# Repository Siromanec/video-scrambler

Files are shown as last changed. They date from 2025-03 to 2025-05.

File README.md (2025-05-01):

# video-scrambler
This repository is for "Development of a Composite Baseband Video Signal (CVBS) scrambler" thesis.

## Description

This project contains:
 - Verilog HDL implementation (Quartus Prime 23.1std project) 
 - simulation setup (Modelsim Starter Edition 2021.1 project)
 - jupyter notebooks for visualization and validation of the algorithms
 - KiCAD 9.0 PCB designs for ADV7393 video encoder and TVP5147M1 video decoder

The Verilog implementation is based around line rotation algorithm for scrambling, 
Hash DRBG and SHA256 for number generation. 
It works with BT656 and SMPTE293M digital signal. 
Can synchronise the PRNGs even when the signal is lost. 
The scrambling pattern is different for each frame.
The number of frames before the pattern repeats is 2^32.
The delay is ~ 10^-8 s

The PCB design has the following features:
 - supplied with \> 5V
 - has 4 layers
 - separated power plains
 - all chips pins were wired to external pins (except chroma pins)
 - equalized paths

## Structure and  use
To open each project you need the corresponding IDE
### Notebooks
#### 1. `notebooks/config_creation`

It contains scripts for generating 256-bit seeds and putting them into `.mif` files for configuring the scrambler.

Generates complementary config files for the scrambler and descramber,
#### 2. `notebooks/functional_validation`
It was used to rewrite high-level python implementation
into verilog-friendly algorithm
#### 3. `notebooks/mp_to_bt656`

It contains a notebook used for converting `.mp4` video to `.bin` file compliant with bt656.

Additionally, it is used for visualization the scrambled and descrambled videos and contains the entropy calculations

Also, it has two videos: `aperol.mp4` and `church.mp4`. 
For simulation the user must convert the videos to
`aperol_f84.bin` and `church_f218.bin` and put them into

`FPGA/core/simulation/modelsim/data` or `FPGA/core/simulation/questa/data`

#### 4. `notebooks/randomness_validation`
It was used to validate that the generated random numbers are random
#### 5. `notebooks/resource_usage`
It was used to produce plots of resource usage as compiled by Quartus

### Verilog HDL implementation

`scrambler_mm` is the top module

`FPGA/core` contains the quartus project

`FPGA/core/src` contains rtl and tb code

`FPGA/core/include` contains rtl written by other developers

### Simulation setup

`FPGA/core/simulation/modelsim` contains the modelsim project

To provide the data for the simulation 
you must put it into `FPGA/core/simulation/modelsim/data`.
currently the simulations accepts only two types of files: files generated from `aperol_f84.bin` or `church_f218.bin`.
if you want to change it, you must modify the testbench with names of your files.
Once they are in there, open the project with `modelsim`, goto `project`, see a `sim` folder and in there run
`de/scrambler_mm_sim`. Run the scrambler first, and then the descrambler.
The results will be in `FPGA/core/simulation/modelsim/data` folder.



`FPGA/core/simulation/questa` is generated by quartus for RTL and Gate Level simulations. 
It was only used for GLS of scrambler_mm, because quartus has a bad interface for simulation, 
when the top module changes frequently.

When doing the GLS the user MUST CHANGE THE MIF FILE (for the corresponding functionality) 
AND UPDATE THE MIF FILE (in quartus) OR RECOMPILE when switching 
between scrambling (scrambler_mm_gls_tb) 
and descrambling(descrambler_mm_gls_tb) simulations. 
This is because in gate level simulation the mif file is compiled into the tested module.

### PCB
`PCB/ADV7393BCPZ_encoder` contains the KiCAD project with the corresponding chip

`PCB/TVP5147M1_decoder` contains the KiCAD project with the corresponding chip 
AND the TVP5147M1_decoder and ADV7393BCPZ_encoder on the same PCB

### Results
It contains scrambled and descrambled videos

scrambled



descrambled



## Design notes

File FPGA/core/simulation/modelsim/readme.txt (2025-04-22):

modelsim replaces relative paths with absolute and that will cause issues on other devices

best solution is to find and replace the

C:/Users/ADMIN/edu/thesis/video-scrambler/FPGA/core

with relative path

../..

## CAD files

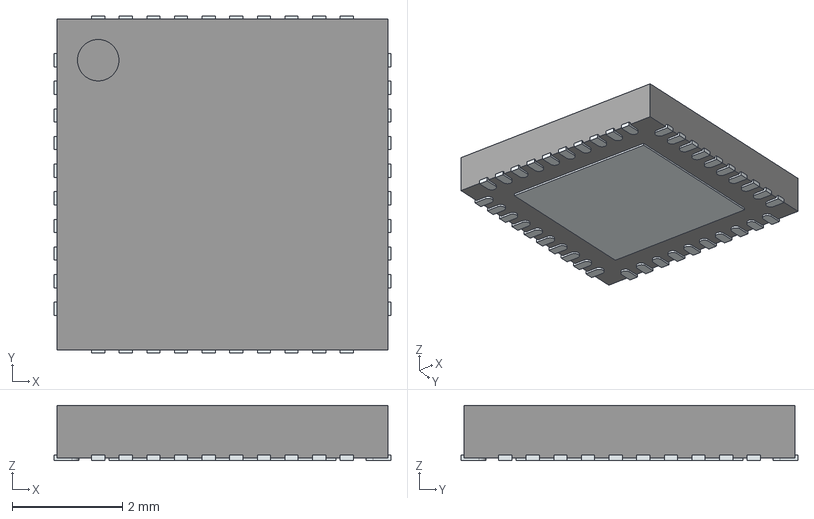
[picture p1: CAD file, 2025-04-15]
PCB/ADV7393BCPZ_encoder/LIB_ADV7393BCPZ-REEL/ADV7393BCPZ-REEL.stp
6.10 x 6.10 x 1.00 mm
ThermalPin
PinsArrayLR
PinsArrayTB

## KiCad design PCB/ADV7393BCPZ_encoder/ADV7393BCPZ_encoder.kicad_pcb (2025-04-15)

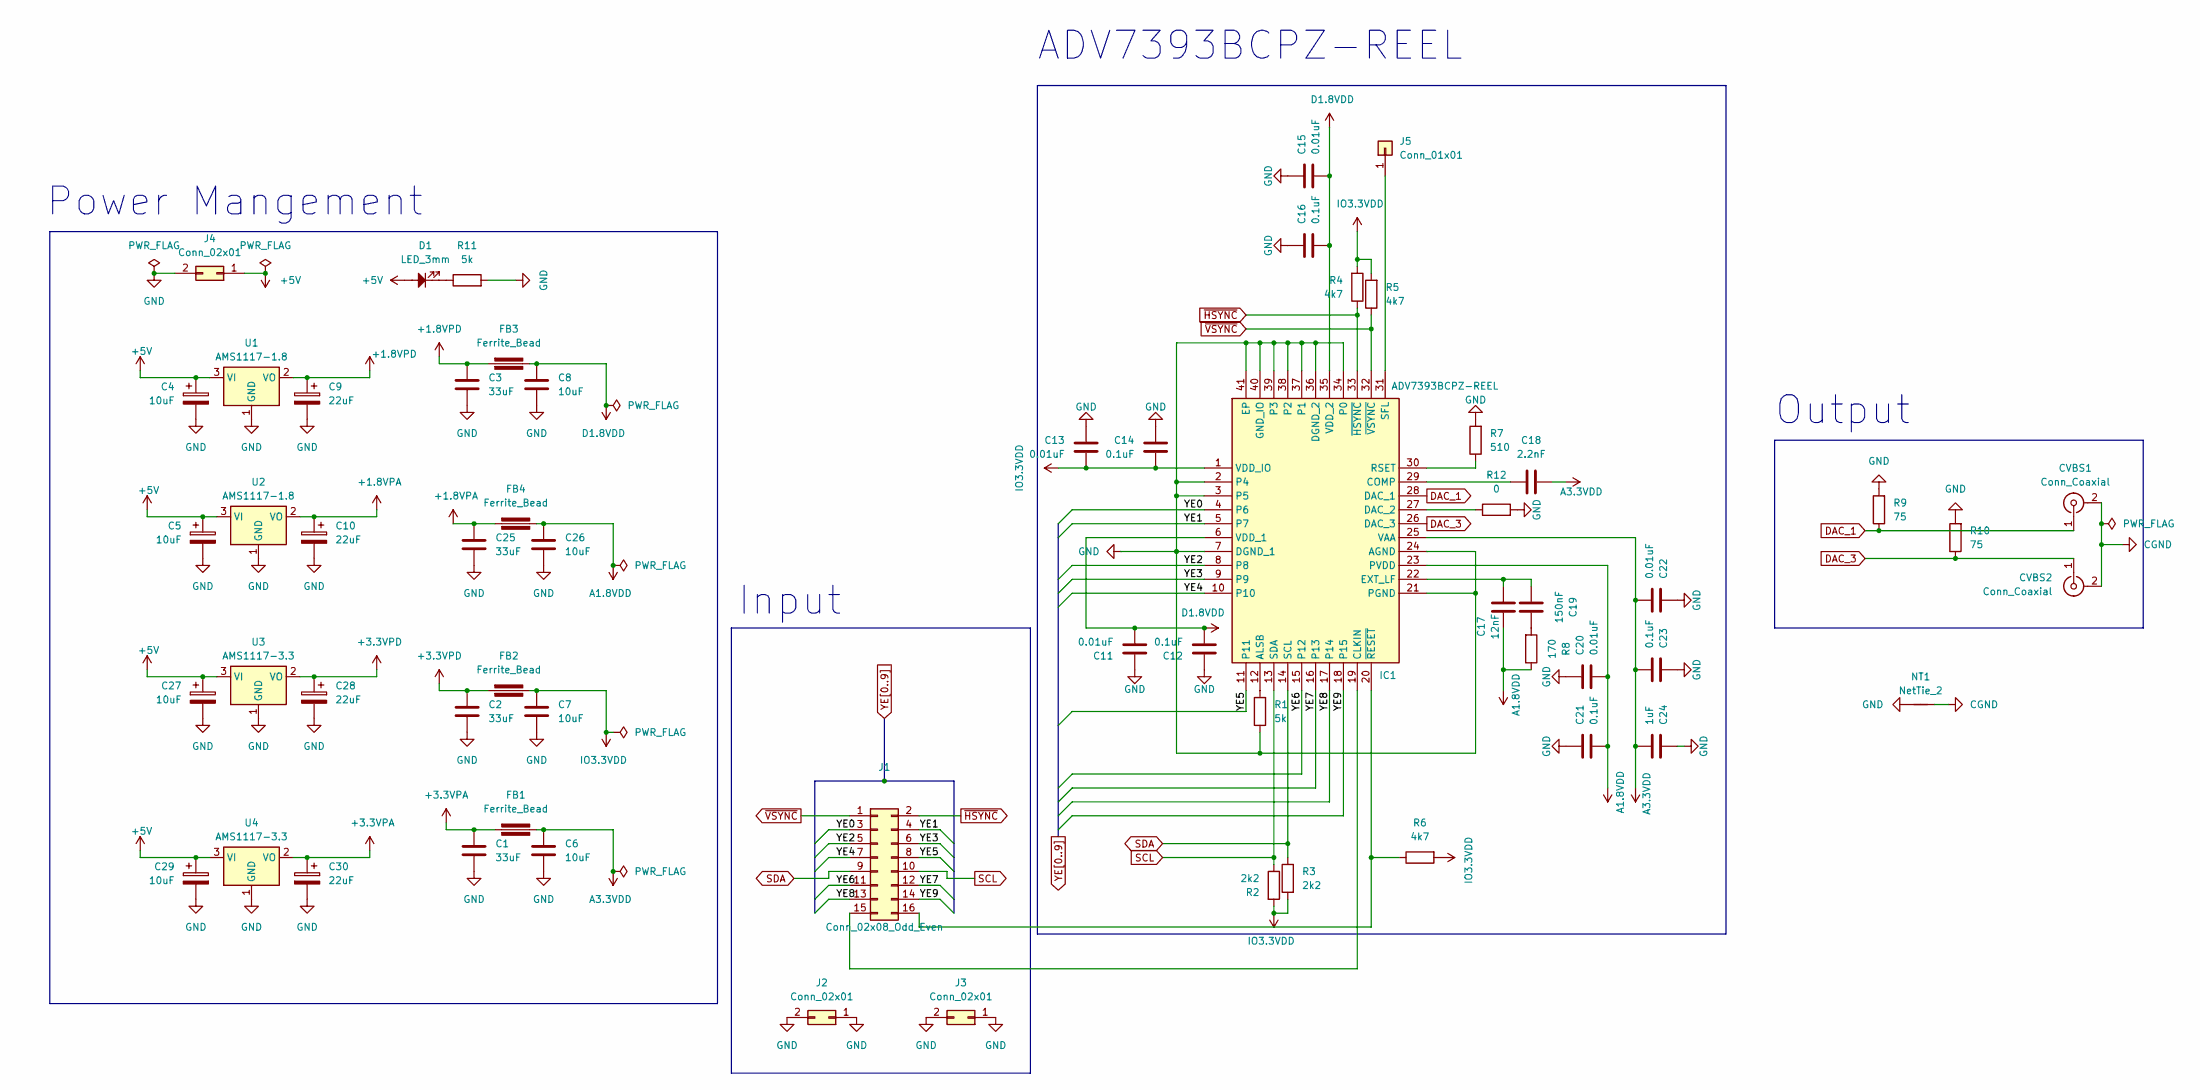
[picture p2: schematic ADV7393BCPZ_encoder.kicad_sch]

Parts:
C1, C2, C3, C25: 33uF; CP_EIA-3528-15_AVX-H_Pad1.50x2.35mm_HandSolder
C4, C5, C27, C29: 10uF; CP_Elec_4x5.7
C6, C7, C8, C26: 10uF; CP_EIA-3216-18_Kemet-A_Pad1.58x1.35mm_HandSolder
C9, C10, C28, C30: 22uF; CP_Elec_5x5.7
C11, C13, C15, C20, C22: 0.01uF; C_0603_1608Metric_Pad1.08x0.95mm_HandSolder
C12, C14, C16, C21, C23: 0.1uF; C_0603_1608Metric_Pad1.08x0.95mm_HandSolder
C17: 12nF; C_0603_1608Metric_Pad1.08x0.95mm_HandSolder
C18: 2.2nF; C_0603_1608Metric_Pad1.08x0.95mm_HandSolder
C19: 150nF; C_0603_1608Metric_Pad1.08x0.95mm_HandSolder
C24: 1uF; CP_EIA-3216-18_Kemet-A_Pad1.58x1.35mm_HandSolder
CVBS1, CVBS2: Conn_Coaxial; CC-132-B1
D1: LED_3mm; LED_D3.0mm
FB1, FB2, FB3, FB4: Ferrite_Bead; Ferrite_L6.0mm_D3.5mm_P10.16mm
IC1: ADV7393BCPZ-REEL; LFCSP-40-1EP_6x6mm_P0.5mm_EP3.9x3.9mm_ThermalVias; Manufacturer_Part_Number ADV7393BCPZ-REEL; Mouser Part Number 584-ADV7393BCPZ-R
J1: Conn_02x08_Odd_Even; PinHeader_2x08_P2.54mm_Vertical
J2, J3, J4: Conn_02x01; PinHeader_2x01_P2.54mm_Vertical
J5: Conn_01x01; PinHeader_1x01_P2.54mm_Vertical
NT1: NetTie_2; NetTie-2_THT_Pad1.0mm
R1: 5k; R_0603_1608Metric_Pad0.98x0.95mm_HandSolder
R2, R3: 2k2; R_0603_1608Metric_Pad0.98x0.95mm_HandSolder
R4, R5, R6: 4k7; R_0603_1608Metric_Pad0.98x0.95mm_HandSolder
R7: 510; R_0603_1608Metric_Pad0.98x0.95mm_HandSolder
R8: 170; R_0603_1608Metric_Pad0.98x0.95mm_HandSolder
R9, R10: 75; R_0603_1608Metric_Pad0.98x0.95mm_HandSolder
R11: 5k; R_0603_1608Metric_Pad1.05x0.95mm_HandSolder
R12: 0; R_0603_1608Metric_Pad0.98x0.95mm_HandSolder
U1, U2: AMS1117-1.8; SOT-223-3_TabPin2
U3, U4: AMS1117-3.3; SOT-223-3_TabPin2

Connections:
+1.8VPA: C10.1, C25.1, FB4.1, U2.2 (VO)
+1.8VPD: C3.1, C9.1, FB3.1, U1.2 (VO)
+3.3VPA: C1.1, C30.1, FB1.1, U4.2 (VO)
+3.3VPD: C2.1, C28.1, FB2.1, U3.2 (VO)
+5V: C4.1, C5.1, C27.1, C29.1, D1.2, J4.1, U1.3 (VI), U2.3 (VI), U3.3 (VI), U4.3 (VI)
A1.8VDD: C17.2, C20.1, C21.2, C26.1, FB4.2, IC1.23 (PVDD), R8.1
A3.3VDD: C6.1, C18.2, C22.1, C23.2, C24.1, FB1.2, IC1.25 (VAA)
CGND: CVBS1.2 (Ext), CVBS2.2 (Ext), NT1.2
D1.8VDD: C8.1, C11.1, C12.2, C15.1, C16.2, FB3.2, IC1.6 (VDD_1), IC1.35 (VDD_2)
DAC_1: CVBS1.1 (In), IC1.28 (DAC_1), R9.1
DAC_3: CVBS2.1 (In), IC1.26 (DAC_3), R10.1
GND: C1.2, C2.2, C3.2, C4.2, C5.2, C6.2, C7.2, C8.2, C9.2, C10.2, C11.2, C12.1, C13.2, C14.1, C15.2, C16.1, C20.2, C21.1, C22.2, C23.1, C24.2, C25.2, C26.2, C27.2, C28.2, C29.2, C30.2, IC1.2 (P4), IC1.3 (P5), IC1.7 (DGND_1), IC1.21 (PGND), IC1.24 (AGND), IC1.34 (P0), IC1.36 (DGND_2), IC1.37 (P1), IC1.38 (P2), IC1.39 (P3), IC1.40 (GND_IO), IC1.41 (EP), J2.1, J2.2, J3.1, J3.2, J4.2, NT1.1, R1.1, R7.2, R9.2, R10.2, R11.2, R12.2, U1.1 (GND), U2.1 (GND), U3.1 (GND), U4.1 (GND)
IO3.3VDD: C7.1, C13.1, C14.2, FB2.2, IC1.1 (VDD_IO), R2.2, R3.2, R4.2, R5.2, R6.2
unnamed: C19.2, R8.2
unnamed: D1.1, R11.1
unnamed: IC1.12 (ALSB), R1.2
unnamed: IC1.19 (CLKIN), J1.15
unnamed: C18.1, IC1.29 (COMP)
unnamed: IC1.27 (DAC_2), R12.1
unnamed: C17.1, C19.1, IC1.22 (EXT_LF)
unnamed: IC1.30 (RSET), R7.1
unnamed: IC1.31 (SFL), J5.1
unnamed: IC1.20 (~RESET), J1.16, R6.1
SCL: IC1.13 (SDA), J1.10, R2.1
SDA: IC1.14 (SCL), J1.9, R3.1
YE0: IC1.4 (P6), J1.3
YE1: IC1.5 (P7), J1.4
YE2: IC1.8, J1.5
YE3: IC1.9, J1.6
YE4: IC1.10, J1.7
YE5: IC1.11, J1.8
YE6: IC1.15 (P12), J1.11
YE7: IC1.16 (P13), J1.12
YE8: IC1.17 (P14), J1.13
YE9: IC1.18 (P15), J1.14
~HSYNC: IC1.33 (~HSYNC), J1.2, R4.1
~VSYNC: IC1.32 (~VSYNC), J1.1, R5.1

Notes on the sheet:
ADV7393BCPZ-REEL
Output
Power Mangement
Input

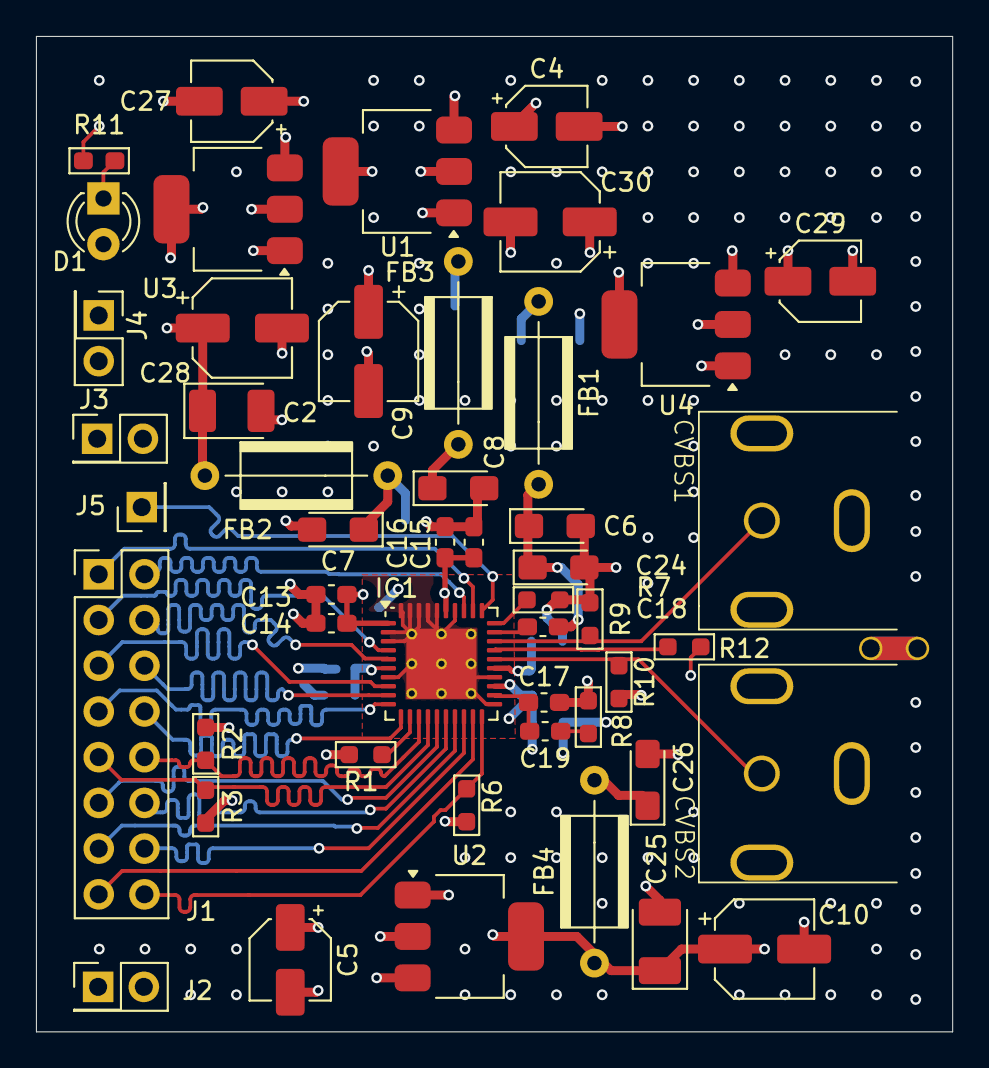
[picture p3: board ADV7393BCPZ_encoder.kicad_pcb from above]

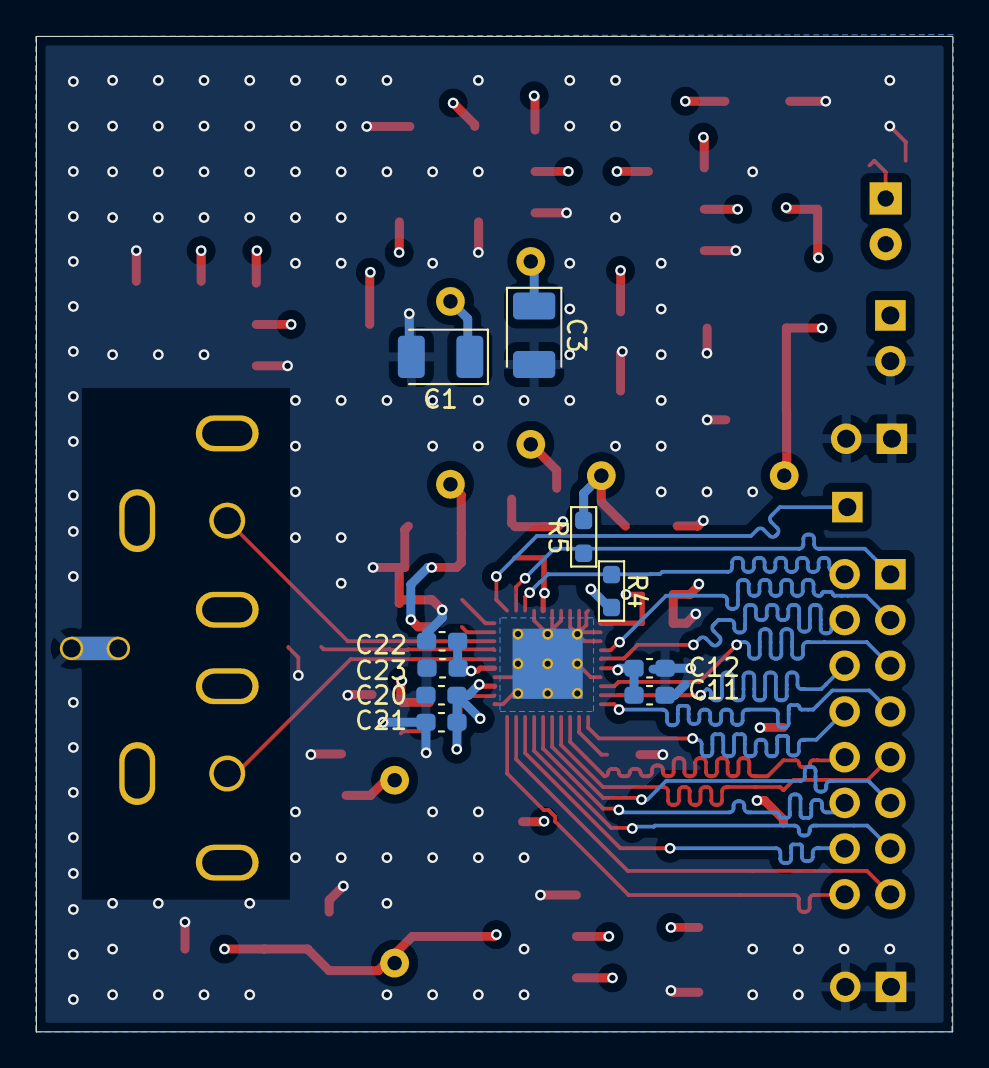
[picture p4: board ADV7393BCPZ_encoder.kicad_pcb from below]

Board: 4 copper layers, 50.9 x 55.3 mm, 60 parts (10 on the bottom side), 37 nets.

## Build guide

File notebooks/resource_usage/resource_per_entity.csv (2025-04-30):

Copyright (C) 2024 Intel Corporation. All rights reserved.
Your use of Intel Corporation's design tools | logic functions
and other software and tools | and any partner logic
functions | and any output files from any of the foregoing
(including device programming or simulation files) | and any
associated documentation or information are expressly subject
to the terms and conditions of the Intel Program License
Subscription Agreement | the Intel Quartus Prime License Agreement
the Intel FPGA IP License Agreement | or other applicable license
agreement | including | without limitation | that your use is for
the sole purpose of programming logic devices manufactured by
Intel and sold by Intel or its authorized distributors. Please
refer to the applicable agreement for further details | at
https://fpgasoftware.intel.com/eula.
Analysis & Synthesis Resource Utilization by Entity
Compilation Hierarchy Node | Combinational ALUTs | Dedicated Logic Registers | Block Memory Bits | DSP Blocks | Pins | Virtual Pins | Full Hierarchy Name | Entity Name | Library Name
|scrambler_mm | 2562 (3) | 2714 (0) | 41728 | 1 | 23 | 0 | |scrambler_mm | scrambler_mm | work
|rom_scrambler_config:rom_scrambler_config0| | 38 (0) | 34 (0) | 512 | 0 | 0 | 0 | |scrambler_mm|rom_scrambler_config:rom_scrambler_config0 | rom_scrambler_config | work
|altsyncram:altsyncram_component| | 38 (0) | 34 (0) | 512 | 0 | 0 | 0 | |scrambler_mm|rom_scrambler_config:rom_scrambler_config0|altsyncram:altsyncram_component | altsyncram | work
|altsyncram_72j1:auto_generated| | 38 (0) | 34 (0) | 512 | 0 | 0 | 0 | |scrambler_mm|rom_scrambler_config:rom_scrambler_config0|altsyncram:altsyncram_component|altsyncram_72j1:auto_generated | altsyncram_72j1 | work
|altsyncram_8kk2:altsyncram1| | 0 (0) | 0 (0) | 512 | 0 | 0 | 0 | |scrambler_mm|rom_scrambler_config:rom_scrambler_config0|altsyncram:altsyncram_component|altsyncram_72j1:auto_generated|altsyncram_8kk2:altsyncram1 | altsyncram_8kk2 | work
|sld_mod_ram_rom:mgl_prim2| | 38 (22) | 34 (25) | 0 | 0 | 0 | 0 | |scrambler_mm|rom_scrambler_config:rom_scrambler_config0|altsyncram:altsyncram_component|altsyncram_72j1:auto_generated|sld_mod_ram_rom:mgl_prim2 | sld_mod_ram_rom | work
|sld_rom_sr:\ram_rom_logic_gen:name_gen:info_rom_sr| | 16 (16) | 9 (9) | 0 | 0 | 0 | 0 | |scrambler_mm|rom_scrambler_config:rom_scrambler_config0|altsyncram:altsyncram_component|altsyncram_72j1:auto_generated|sld_mod_ram_rom:mgl_prim2|sld_rom_sr:\ram_rom_logic_gen:name_gen:info_rom_sr | sld_rom_sr | work
|rom_scrambler_config_reader:rom_scrambler_config_reader0| | 58 (58) | 266 (266) | 0 | 0 | 0 | 0 | |scrambler_mm|rom_scrambler_config_reader:rom_scrambler_config_reader0 | rom_scrambler_config_reader | work
|scrambler:scrambler_inst| | 2362 (24) | 2328 (0) | 41216 | 1 | 0 | 0 | |scrambler_mm|scrambler:scrambler_inst | scrambler | work
|delay_buffer_4clk:delay_stream| | 16 (16) | 52 (52) | 0 | 0 | 0 | 0 | |scrambler_mm|scrambler:scrambler_inst|delay_buffer_4clk:delay_stream | delay_buffer_4clk | work
|drbg_consumer:drbg_consumer_inst| | 127 (127) | 27 (27) | 256 | 0 | 0 | 0 | |scrambler_mm|scrambler:scrambler_inst|drbg_consumer:drbg_consumer_inst | drbg_consumer | work
|altsyncram:data_buffer_rtl_0| | 0 (0) | 0 (0) | 256 | 0 | 0 | 0 | |scrambler_mm|scrambler:scrambler_inst|drbg_consumer:drbg_consumer_inst|altsyncram:data_buffer_rtl_0 | altsyncram | work
|altsyncram_qsj1:auto_generated| | 0 (0) | 0 (0) | 256 | 0 | 0 | 0 | |scrambler_mm|scrambler:scrambler_inst|drbg_consumer:drbg_consumer_inst|altsyncram:data_buffer_rtl_0|altsyncram_qsj1:auto_generated | altsyncram_qsj1 | work
|hash_drbg_sha256:hash_drbg_sha256_0| | 2008 (1) | 2139 (0) | 0 | 0 | 0 | 0 | |scrambler_mm|scrambler:scrambler_inst|hash_drbg_sha256:hash_drbg_sha256_0 | hash_drbg_sha256 | work
|hash_drbg:master_drbg| | 857 (857) | 1101 (1101) | 0 | 0 | 0 | 0 | |scrambler_mm|scrambler:scrambler_inst|hash_drbg_sha256:hash_drbg_sha256_0|hash_drbg:master_drbg | hash_drbg | work
|posedge_to_pulse:b2v_inst12| | 1 (1) | 2 (2) | 0 | 0 | 0 | 0 | |scrambler_mm|scrambler:scrambler_inst|hash_drbg_sha256:hash_drbg_sha256_0|posedge_to_pulse:b2v_inst12 | posedge_to_pulse | work
|posedge_to_pulse:b2v_inst14| | 2 (2) | 2 (2) | 0 | 0 | 0 | 0 | |scrambler_mm|scrambler:scrambler_inst|hash_drbg_sha256:hash_drbg_sha256_0|posedge_to_pulse:b2v_inst14 | posedge_to_pulse | work
|sha256_core:b2v_inst5| | 1147 (525) | 1034 (522) | 0 | 0 | 0 | 0 | |scrambler_mm|scrambler:scrambler_inst|hash_drbg_sha256:hash_drbg_sha256_0|sha256_core:b2v_inst5 | sha256_core | work
|sha256_k_constants:k_constants_inst| | 32 (32) | 0 (0) | 0 | 0 | 0 | 0 | |scrambler_mm|scrambler:scrambler_inst|hash_drbg_sha256:hash_drbg_sha256_0|sha256_core:b2v_inst5|sha256_k_constants:k_constants_inst | sha256_k_constants | work
|sha256_w_mem:w_mem_inst| | 590 (590) | 512 (512) | 0 | 0 | 0 | 0 | |scrambler_mm|scrambler:scrambler_inst|hash_drbg_sha256:hash_drbg_sha256_0|sha256_core:b2v_inst5|sha256_w_mem:w_mem_inst | sha256_w_mem | work
|line_rotator:line_rotator_inst| | 132 (125) | 36 (36) | 40960 | 1 | 0 | 0 | |scrambler_mm|scrambler:scrambler_inst|line_rotator:line_rotator_inst | line_rotator | work
|altsyncram:line_buffer_rtl_0| | 0 (0) | 0 (0) | 40960 | 0 | 0 | 0 | |scrambler_mm|scrambler:scrambler_inst|line_rotator:line_rotator_inst|altsyncram:line_buffer_rtl_0 | altsyncram | work
|altsyncram_ecn1:auto_generated| | 0 (0) | 0 (0) | 40960 | 0 | 0 | 0 | |scrambler_mm|scrambler:scrambler_inst|line_rotator:line_rotator_inst|altsyncram:line_buffer_rtl_0|altsyncram_ecn1:auto_generated | altsyncram_ecn1 | work
|cut_position_interpolator:cut_position_interpolator_inst| | 7 (7) | 0 (0) | 0 | 1 | 0 | 0 | |scrambler_mm|scrambler:scrambler_inst|line_rotator:line_rotator_inst|cut_position_interpolator:cut_position_interpolator_inst | cut_position_interpolator | work
|sequence_generator:sequence_generator_inst| | 15 (1) | 46 (1) | 0 | 0 | 0 | 0 | |scrambler_mm|scrambler:scrambler_inst|sequence_generator:sequence_generator_inst | sequence_generator | work
|clk_div36:clkdiv0| | 5 (5) | 5 (5) | 0 | 0 | 0 | 0 | |scrambler_mm|scrambler:scrambler_inst|sequence_generator:sequence_generator_inst|clk_div36:clkdiv0 | clk_div36 | work
|sequence_shiftreg_out:sequence_shiftreg_out_inst| | 9 (0) | 40 (0) | 0 | 0 | 0 | 0 | |scrambler_mm|scrambler:scrambler_inst|sequence_generator:sequence_generator_inst|sequence_shiftreg_out:sequence_shiftreg_out_inst | sequence_shiftreg_out | work
|lpm_shiftreg:LPM_SHIFTREG_component| | 9 (9) | 40 (40) | 0 | 0 | 0 | 0 | |scrambler_mm|scrambler:scrambler_inst|sequence_generator:sequence_generator_inst|sequence_shiftreg_out:sequence_shiftreg_out_inst|lpm_shiftreg:LPM_SHIFTREG_component | lpm_shiftreg | work
|sequence_generator_switch:sequence_generator_switch_inst| | 24 (24) | 19 (19) | 0 | 0 | 0 | 0 | |scrambler_mm|scrambler:scrambler_inst|sequence_generator_switch:sequence_generator_switch_inst | sequence_generator_switch | work
|sync_parser:sync_parser_current| | 9 (9) | 5 (5) | 0 | 0 | 0 | 0 | |scrambler_mm|scrambler:scrambler_inst|sync_parser:sync_parser_current | sync_parser | work
|sync_parser:sync_parser_delayed| | 7 (7) | 4 (4) | 0 | 0 | 0 | 0 | |scrambler_mm|scrambler:scrambler_inst|sync_parser:sync_parser_delayed | sync_parser | work
|sld_hub:auto_hub| | 101 (1) | 86 (0) | 0 | 0 | 0 | 0 | |scrambler_mm|sld_hub:auto_hub | sld_hub | altera_sld
|alt_sld_fab_with_jtag_input:\instrumentation_fabric_with_node_gen:fabric_gen_new_way:with_jtag_input_gen:instrumentation_fabric| | 100 (0) | 86 (0) | 0 | 0 | 0 | 0 | |scrambler_mm|sld_hub:auto_hub|alt_sld_fab_with_jtag_input:\instrumentation_fabric_with_node_gen:fabric_gen_new_way:with_jtag_input_gen:instrumentation_fabric | alt_sld_fab_with_jtag_input | altera_sld
|alt_sld_fab:instrumentation_fabric| | 100 (0) | 86 (0) | 0 | 0 | 0 | 0 | |scrambler_mm|sld_hub:auto_hub|alt_sld_fab_with_jtag_input:\instrumentation_fabric_with_node_gen:fabric_gen_new_way:with_jtag_input_gen:instrumentation_fabric|alt_sld_fab:instrumentation_fabric | alt_sld_fab | alt_sld_fab
|alt_sld_fab_alt_sld_fab:alt_sld_fab| | 100 (1) | 86 (5) | 0 | 0 | 0 | 0 | |scrambler_mm|sld_hub:auto_hub|alt_sld_fab_with_jtag_input:\instrumentation_fabric_with_node_gen:fabric_gen_new_way:with_jtag_input_gen:instrumentation_fabric|alt_sld_fab:instrumentation_fabric|alt_sld_fab_alt_sld_fab:alt_sld_fab | alt_sld_fab_alt_sld_fab | alt_sld_fab
|alt_sld_fab_alt_sld_fab_sldfabric:sldfabric| | 99 (0) | 81 (0) | 0 | 0 | 0 | 0 | |scrambler_mm|sld_hub:auto_hub|alt_sld_fab_with_jtag_input:\instrumentation_fabric_with_node_gen:fabric_gen_new_way:with_jtag_input_gen:instrumentation_fabric|alt_sld_fab:instrumentation_fabric|alt_sld_fab_alt_sld_fab:alt_sld_fab|alt_sld_fab_alt_sld_fab_sldfabric:sldfabric | alt_sld_fab_alt_sld_fab_sldfabric | alt_sld_fab
|sld_jtag_hub:\jtag_hub_gen:real_sld_jtag_hub| | 99 (66) | 81 (53) | 0 | 0 | 0 | 0 | |scrambler_mm|sld_hub:auto_hub|alt_sld_fab_with_jtag_input:\instrumentation_fabric_with_node_gen:fabric_gen_new_way:with_jtag_input_gen:instrumentation_fabric|alt_sld_fab:instrumentation_fabric|alt_sld_fab_alt_sld_fab:alt_sld_fab|alt_sld_fab_alt_sld_fab_sldfabric:sldfabric|sld_jtag_hub:\jtag_hub_gen:real_sld_jtag_hub | sld_jtag_hub | work
|sld_rom_sr:hub_info_reg| | 14 (14) | 9 (9) | 0 | 0 | 0 | 0 | |scrambler_mm|sld_hub:auto_hub|alt_sld_fab_with_jtag_input:\instrumentation_fabric_with_node_gen:fabric_gen_new_way:with_jtag_input_gen:instrumentation_fabric|alt_sld_fab:instrumentation_fabric|alt_sld_fab_alt_sld_fab:alt_sld_fab|alt_sld_fab_alt_sld_fab_sldfabric:sldfabric|sld_jtag_hub:\jtag_hub_gen:real_sld_jtag_hub|sld_rom_sr:hub_info_reg | sld_rom_sr | work
|sld_shadow_jsm:shadow_jsm| | 19 (19) | 19 (19) | 0 | 0 | 0 | 0 | |scrambler_mm|sld_hub:auto_hub|alt_sld_fab_with_jtag_input:\instrumentation_fabric_with_node_gen:fabric_gen_new_way:with_jtag_input_gen:instrumentation_fabric|alt_sld_fab:instrumentation_fabric|alt_sld_fab_alt_sld_fab:alt_sld_fab|alt_sld_fab_alt_sld_fab_sldfabric:sldfabric|sld_jtag_hub:\jtag_hub_gen:real_sld_jtag_hub|sld_shadow_jsm:shadow_jsm | sld_shadow_jsm | altera_sld

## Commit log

2025-03-09 finished i2c
2025-03-09 i2c changes
2025-03-09 stole someone's i2c
2025-03-10 assembled init module
    [c5_pin_model_dump.txt]
2025-03-15 basic pcb
    [TVP5147M1_decoder.kicad_pcb, TVP5147M1_decoder.kicad_sch]
2025-03-17 decoder pcb almost done
    [TVP5147M1_decoder-B_Cu.gbr, TVP5147M1_decoder-B_Mask.gbr, TVP5147M1_decoder-B_Paste.gbr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]
2025-03-24 added basic hash_drbg
    [TVP5147M1_decoder-B_Cu.gbr, TVP5147M1_decoder-B_Mask.gbr, TVP5147M1_decoder-B_Paste.gbr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]
2025-03-26 hash_drbg is working, trying to add double_hash_drbg
    [TVP5147M1_decoder.kicad_pcb, TVP5147M1_decoder_interface.smp_dump.txt]
2025-03-29 sequence generator works as intended now
    [TVP5147M1_decoder.kicad_pcb]
2025-03-30 sequence detector is working
    [TVP5147M1_decoder_interface.smp_dump.txt]
2025-04-03 cut position interpolator works
2025-04-06 made it so that the cut position won't change until the end of hsync. It should make the line rotator more decoupled from the outside
2025-04-08 wrote and tested hash drbg consumer; needs randomness test just to be sure; works independently of sample count in a line and does not depend on number of lines;
2025-04-14 final scrambler assembled. line rotator in scrambling mode needed to delay the V signal. Modelsim did some magic 0-tick pulses that broke everything
2025-04-14 fixed off-by-one error in switch and logical error in synchronisator
2025-04-14 final scrambler and descrambler assembled and they work flawlessly. Descrambler can catch up to the scrambled video at any point. Thinking whether I should leave conditional compilation for scrambler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
2025-04-15 added memory initialization interface for the scrambler, reduced the number of LUTs used by the drbg, added design files for the video decoder, added scripts for generating keys and uploading them to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
    [ADV7393BCPZ-REEL.stp, ADV7393BCPZ_encoder.kicad_pcb, ADV7393BCPZ_encoder.kicad_sch]
2025-04-22 renamed the project
    [c5_pin_model_dump.txt]
2025-04-24 better frame and entropy visualizations
2025-04-24 moved and added resource usage
    [resource_per_entity.csv]
2025-04-26 added testbenches and configs for scrambler_mm
    [resource_per_entity.csv]
2025-04-30 added chages relating GLS, so that it would work and debug outputs for the scrambler
    [resource_per_entity.csv]
